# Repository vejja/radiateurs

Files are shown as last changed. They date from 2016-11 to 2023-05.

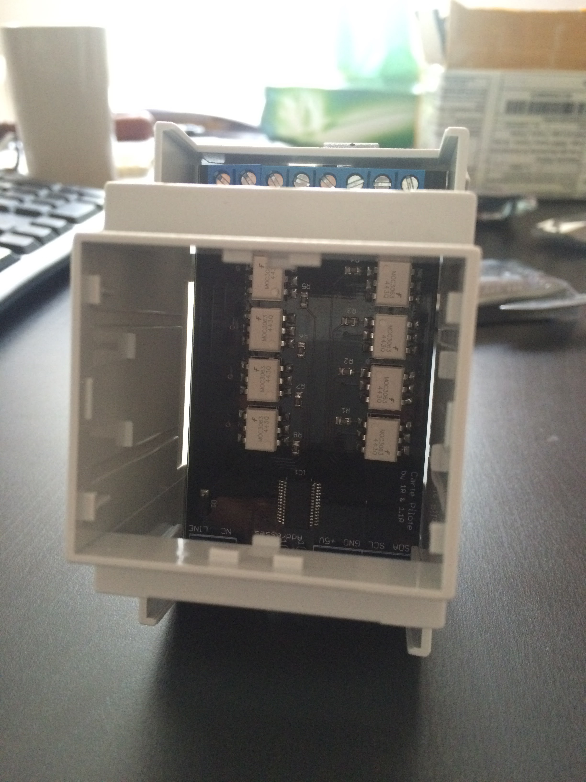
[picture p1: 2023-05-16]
hardware/boitier/IMG_2059.JPG

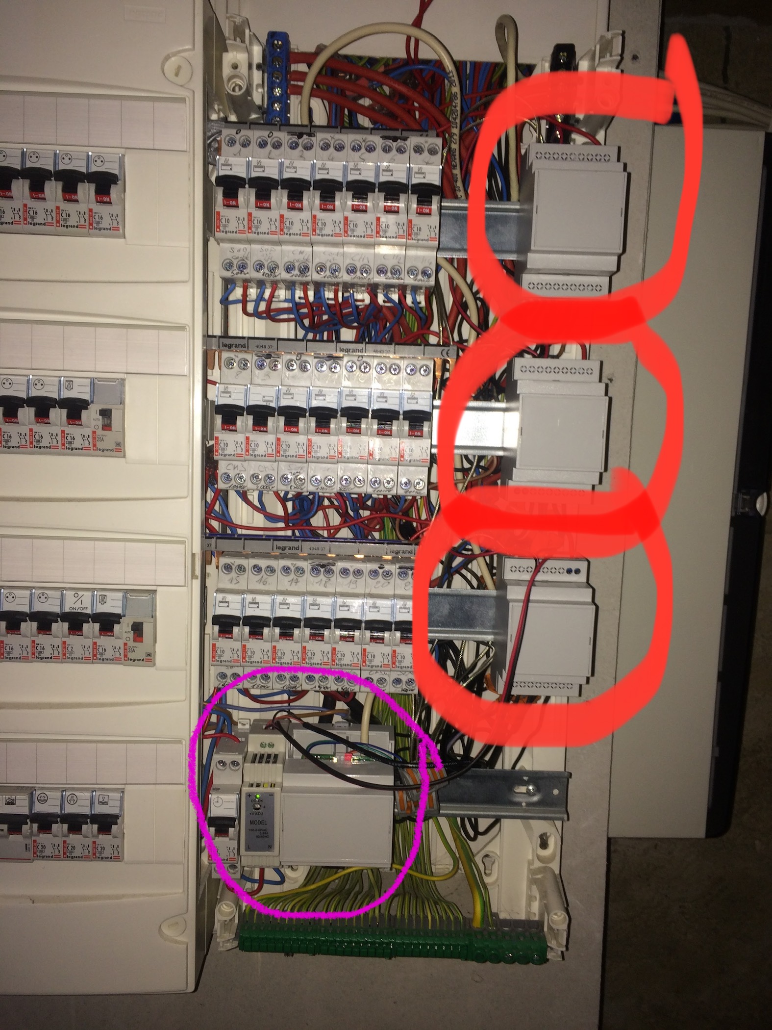
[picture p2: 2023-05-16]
hardware/IMG_2318.jpg

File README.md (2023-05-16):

# README #

## Overview

### Le système complet comprend 3 composants

1. Un frontend client Ionic

Le frontend communique avec le backend essentiellement par Websocket

2. Un backend server NodeJS

Le serveur implémente le protocole Websocket
L'architecture repose sur un Raspberry PI et est composée des couches suivantes:
- nginx (SSL via let's encrypt, forwarde vers node)
- forever (relance node en cas d'arrêt, initialisé dans un RC script)
- NodeJS (websocket listen + reply + commande le Raspberry PI)
- une database sqlite qui stocke les données historiques
 
3. Un module hardware

Il est composé de : 1 convertisseur UART + 1 Raspberry PI + 1 carte pilote I2C radiateurs

- L'info du compteur EDF (téléinfo) doit d'abord être convertie au format UART
- Le Raspberry PI a un port entrée UART qui est utilisé pour lire les données EDF en temps réel
- Le Raspberry PI a un port sortie I2C qui est relié à une carte "Pilote" de contrôle des radiateurs individuels
- La carte Pilote convertit le signal bas voltage I2C du Raspberry PI en 8 sorties distinctes 220V grâce à 16 (2*8) optocoupleurs. A Erquy il y a 3 cartes Pilote (triphasé: une par phase)

### Au final, le Raspberry PI effectue plusieurs tâches simultanées:

- Serveur du code client statique
- Serveur websocket backend, applique les commandes de l'utilisateur
- Ecoute en continu le port entrée UART pour détecter les pics de consommation
- Ecrit sur le port de sortie I2C : allume et éteint les radiateurs (soit en manuel sur commande utilisateur, soit en automatique pour délester en cas de sur consommation)

Instructions pour installer le serveur radiateurs

## Installation Raspberry Pi ##

* Download Raspberry Pi Raspbian Jessie image
* Install

### sudo raspi-config
* Expand Filesystem
* Locale : fr-utf8
* Timezone : Europe/Paris
* Keyboard : French
* Change password
* Enable SSH
* Enable I2C
* Disable shell on serial connection
* Boot into CLI
* Wait for Network at Boot
* sudo reboot

### Wifi configuration
``` 
sudo nano /etc/wpa-supplicant/wpa-supplicant.conf
* network={
        ssid="****"
        psk="****"
        key_mgmt=WPA-PSK
}
sudo timedatectl set-ntp true
```

### Install major utilities
```
sudo apt-get install git nginx sqlite3 ddclient
```

### Install LetsEncrypt
```
git clone https://github.com/letsencrypt/letsencrypt
cd letsencrypt
./letsencrypt-auto --help
```

Check that `letsencrypt`is executable from the command line

If not: `sudo ln -s ~/.local/share/letsencrypt/bin/letsencrypt /usr/local/bin/letsencrypt`

### Download node.js ARMv6 binaries from nodejs.org
```
npm install -g bower
npm install -g forever
npm install -g nodemon
npm install -g node-inspector
```

Check that node utilities are executable from the command line

If not: `sudo ln -s /opt/node/bin/<executable> /usr/local/bin/<executable>`

### Symlink config files
| Config file  | Repo Script | Description |
|---|---|---|
| /etc/ddclient.conf | ddclient.conf | *ddclient* keeps the dyndns record up to date with the IP address of the Livebox |
| /etc/nginx/nginx.conf | nginx.conf | websocket upstream definition |
| /etc/nginx/sites-available/default | default | SSL, Basic auth, websocket proxy forward |
| /etc/rc.local | rc.local | Boot script that launches the serial UART interface & the forever daemon that keeps node.js live in spite of crashes |

### Launch letsencrypt
```
cd radiateurs/server/scripts
./setup-certificate.sh
```

Then `sudo crontab -e` and add the line `30 3 * * * /home/pi/radiateurs/server/scripts/renew-certificate.sh >> /var/log/letsencrypt/cronjob.log`

### Check ttyAMA0 and i2c

```
cat /dev/ttyAMA0
gpio i2cd
```

If needed : 

`sudo nano /boot/cmdline.txt`

* Supprimer console=ttyAMA0,115200 kgdboc=ttyAMA0,115200

`sudo nano /etc/modules`

* i2c-bcm2708 
* i2c-dev

`sudo nano /boot/config.txt`

* dtparam=i2c=on
* dtparam=i2c_arm=on

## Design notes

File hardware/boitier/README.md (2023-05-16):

# Boitier plastique

Ce boîtier plastique sur SketchUp permettait d'abriter un module Carte Pilote et de le fixer sur rail DIN dans un compteur EDF. L'idée était de l'imprimer en 3D.

Au final j'ai acheté un boitier DIN standard et j'ai dessiné le PCB de la carte pilote pour qu'elle rentre dedans. C'est plus sûr électriquement d'utiliser un boîtier industriel (c'est quand même du 220V là dedans)

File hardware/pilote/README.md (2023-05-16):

# Carte Pilote

TODO : retrouver les schémas EAGLE du PCB

- Ressources: https://www.planete-domotique.com/blog/2012/01/05/piloter-un-radiateur-grace-a-son-fil-pilote/
- gerber: Fichier Gerber d'impression du PCB
- BOMFile: Bon de commande des composants électroniques
- Principes des ordres 220V du fil pilote
- Photos

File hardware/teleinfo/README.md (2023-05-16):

# Module Teleinfo

Ressources:
https://www.magdiblog.fr/gpio/teleinfo-edf-suivi-conso-de-votre-compteur-electrique/

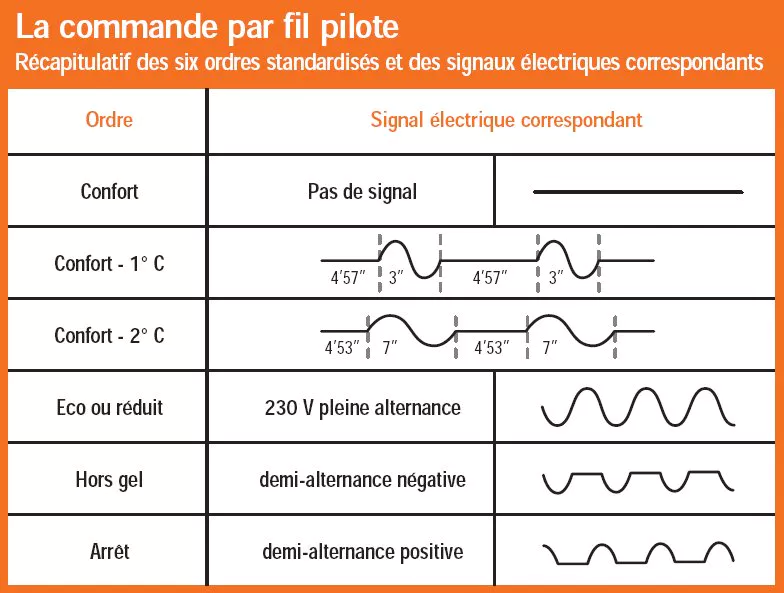
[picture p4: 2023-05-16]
hardware/pilote/ordre_fil_pilote.jpg.webp

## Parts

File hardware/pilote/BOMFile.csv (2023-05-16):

Quantity | Name | Value | Package | Manufacturer | Manuf. Code | Digikey P/N | Description
2 | D1, D2 | S1M | SMA | FAIRCHILD | S1M | S1MFSCT-ND | STANDARD DIODE, 1A, 1000V
1 | IC1 | MCP23017SS | SSOP28 | MICROCHIP | MCP23017-E/SS | MCP23017-E/SS-ND | IC, I2C EXPANDER 16BIT, SMD
16 | OC1 - OC16 | MOC3063S | 6-SMD | LITE-ON | MOC3063S-TA1 | 160-1723-1-ND | OPTOCOUPLER WITH TRIAC OUTPUT
16 | R1 - R16 | 560 | R0805 | PANASONIC | ERJ-6GEYJ561V | P560ACT-ND | RESISTOR 560R 0.125W 1% 0805 CMS
3 | B1 - B3 | 2WAY |  | ON SHORE TECH | OSTTC022162 | ED2609-ND | PCB SCREW TERMINAL, 2-WAY, VERTICAL, 5.08 PITCH, 22-12AWG
1 | B4 | 8WAY |  | ON SHORE TECH | OSTTC082162 | ED2615-ND | PCB SCREW TERMINAL, 8-WAY, VERTICAL, 5.08 PITCH, 22-12AWG
3 | J1 - J3 | JMP |  | HARWIN | M20-9990346 | 952-2264-ND | 3-PIN HEADER, 0.100, 2.54 PITCH

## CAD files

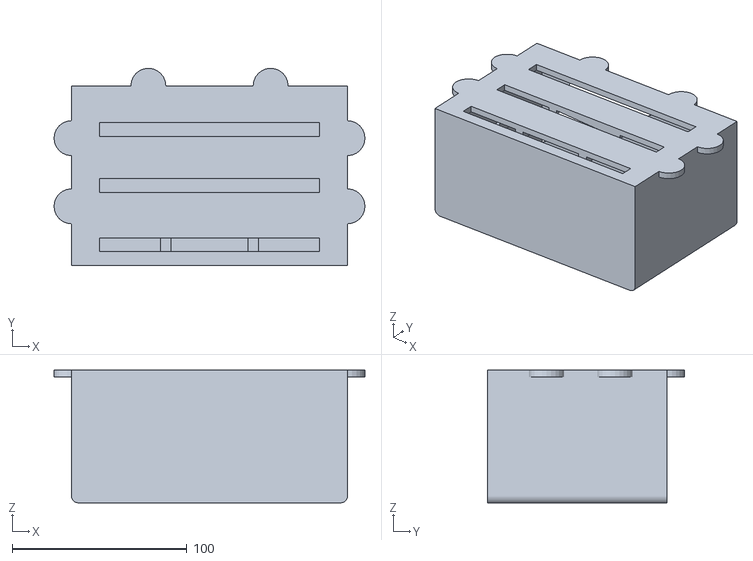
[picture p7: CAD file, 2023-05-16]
hardware/boitier/sketchup/Grouper_1.obj
178.0 x 113.0 x 76.0

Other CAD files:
hardware/boitier/sketchup/ControlBoard.skp
hardware/boitier/sketchup/EnregistrementAuto_ControlBoard.skp
hardware/boitier/sketchup/EnregistrementAuto_FullControlKit v3.skp
hardware/boitier/sketchup/EnregistrementAuto_FullControlKit.skp
hardware/boitier/sketchup/FullControlKit v2.skp
hardware/boitier/sketchup/FullControlKit v3.skp
hardware/boitier/sketchup/FullControlKit.skp
hardware/boitier/sketchup/Grouper_1.skp
hardware/boitier/sketchup/M6_Thread.skp
hardware/boitier/sketchup/Pasdevis_M4_5mm.skp
hardware/boitier/sketchup/Phillips-Countersunk-Head-Screw-metric.skp
hardware/boitier/sketchup/Phillips_Countersunk_Head_Screw.skp
hardware/boitier/sketchup/Rectangle.skp

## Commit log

2016-10-26 insert ticks table in db
2016-10-27 get params and insert params
2016-10-27 it is row which is null in that case
2016-11-13 add powerHistory
2016-11-13 modify powerHistory ws type
2016-11-13 powerHistory on client side only
2016-11-14 i2cbus private
2016-11-14 try power

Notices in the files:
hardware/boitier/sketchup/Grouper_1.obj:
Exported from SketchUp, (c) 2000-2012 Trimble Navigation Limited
